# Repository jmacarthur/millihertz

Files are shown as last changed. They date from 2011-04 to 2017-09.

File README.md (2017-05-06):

# Millihertz mechanical computing repository

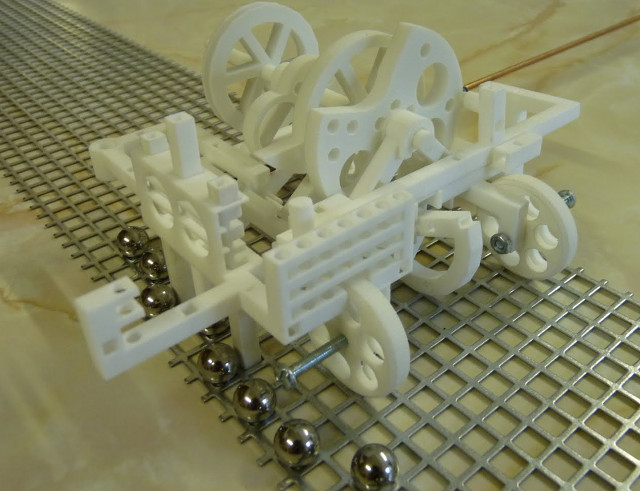
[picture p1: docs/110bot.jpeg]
3D printed rule 110 robot


This is a repository of CAD/CAM parts and text descriptions for mechanical and unusual computing.

* Diagrams: 2D explanatory diagrams, usually for documentation.
* scad: Models used to make Turing machine.
* scad/old: Plans for my first Turing machine, which was largely handmade. Only the 'maze' part of this was actually used in the finished machine.
* scad/newbuild: Plans for the V2 Turing machine, which was laser-cut. The finished V2 machine was closer to the plans, but some post-cutting modifications were still necessary.
* scad/110: Plans for two verions of the rule 110 automaton; one intended for 3d printing and one for laser cutting.

Please note that none of the plans in here are intended for people to make directly. They are likely to be unfinished and contain errors. They are also not very well documented, which may improve over time.

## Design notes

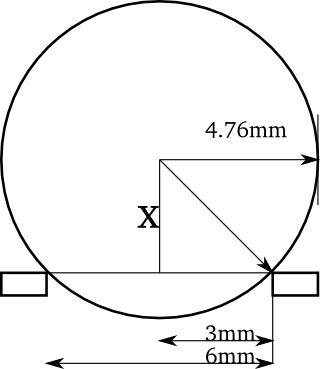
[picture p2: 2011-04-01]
diagrams/ingress.png

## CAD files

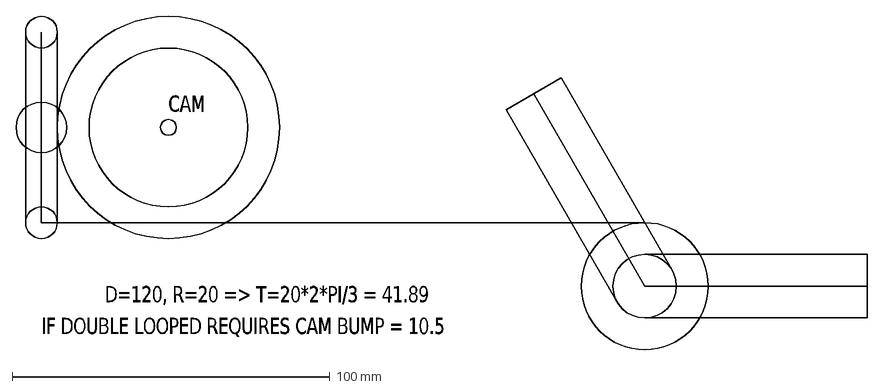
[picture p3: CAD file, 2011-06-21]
diagrams/lifter.dxf
D=120,\~R=20\~=>\~T=20*2*PI/3\~=\~41.89
CAM
IF\~DOUBLE\~LOOPED\~REQUIRES\~CAM\~BUMP\~=\~10.5

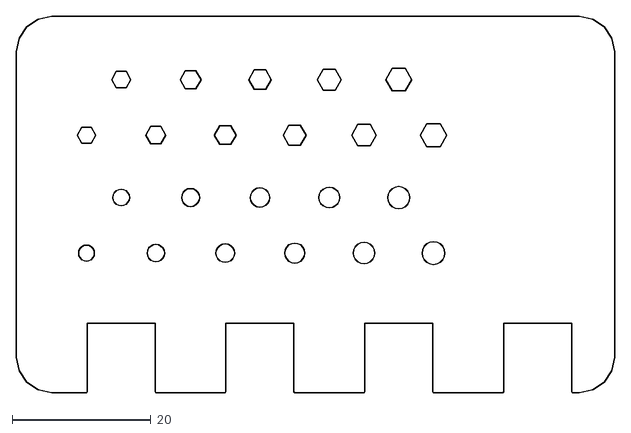
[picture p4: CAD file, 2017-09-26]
scad/laser_test/laser_test_kerf_0.1.dxf
86.2 x 54.2

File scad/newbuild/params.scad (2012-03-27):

// This file should only contain constants (no objects)
// All measurements are in mm

// Grid parameters. This is for 6mm square hole galvanised grid
// RS stock number 210-3729
gridThickness = 1.4; // That's two grid plates on top of each other
gridSpacing = 7.58; // That's the period of the grid, not the hole size
	            // Measured from actual grid
gridHoleSize = 6;
gridWallWidth = gridSpacing - gridHoleSize;


mazeWidth = 115+12;
mazeHeight = 35;
mazeLength = 97;
mazeStartY = 0;

// These define the location of the holes for the raiser axles.
mazeHoleOffsetY = 76.5;
mazeHoleOffsetZ = 13;

dirBoxHeight=10;
dirBoxWallWidth=5;

stateBoxHeight=22;
stateBoxWallWidth=5;

ballRadius = 4.76;

// ballBearingHeight is the top of any ball bearing sitting in the grid.
ballBearingHeight = sqrt(ballRadius*ballRadius - (gridHoleSize/2)*(gridHoleSize/2)) + gridThickness + ballRadius;

// row1x is the X coordinate of the centre of the first row of ball bearings
row1x = gridSpacing*5+gridWallWidth + gridHoleSize/2;
echo("row1x is ",row1x);
// Measured from the original machine
chassisInternalSpacing = 95;
chassisWallThickness = 1.5;
chassisThickness = 20;

wheelDiameter = 37.5;
wheelRadius = wheelDiameter/2;
wheelWidth = 6; // Should be <= gridHoleSize
axleDiameter = 3;
axleRadius = axleDiameter/2;
wheelIngress = sqrt((wheelRadius*wheelRadius)-(gridHoleSize/2)*(gridHoleSize/2));
axleHeight = wheelIngress + gridThickness;

chassisStartX = gridWallWidth+wheelWidth;

chassisTop = axleHeight+axleRadius+chassisThickness;
rideHeight = chassisTop - chassisThickness;

// Standard roller bearing, 5mm bore, 16mm OD
bearingWidth = 5;
bearingRadius = 8;

// Needle roller bearing, 12mm bore, 10mm wide, 16mm OD
// Technobots 4250-007
needleRollerRadius = 8;
needleRollerWidth=10;

raiserWallWidth = 3;
raiserSeparation = 1;
mazeStartX =  gridWallWidth+wheelWidth+chassisThickness-(mazeWidth-chassisInternalSpacing)/2;

axle1Y = gridSpacing*12;
axle2Y = gridSpacing*39;
axleBlockThickness = 3;
axleBearingDiameter = 6; // These are technobots mini bearings, code 4255-020

// Laser beam diameter
// This is set to zero because I expect to account for the laser cut width
// outside OpenSCAD (in InkScape, probably)
cutWidth=0;

// This is used to make things slightly bigger for CSG, to avoid touching walls.
thin = 0.1;

mazeTop = chassisTop+mazeHeight-5;

dirBoxOffsetY = gridSpacing*4-dirBoxWallWidth/2; 
dirBoxOffsetX = row1x-dirBoxWallWidth-gridSpacing; // Offset from the edge of the grid to the dir box

boxWidth = 4.76; // Width of box section used as cam axle

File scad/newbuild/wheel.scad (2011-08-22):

include <params.scad>

// Defines wheels for the Turing machine. Wheels need to fit into holes
// in the grid to provide some keying for the machine's position.

// Wheels are Z adjusted to ride on a double-thickness grid. X,Y are adjusted so without translation, the wheel will fit into the grid hole nearest (0,0).

// The wheels used on the first Turing machine were 37mm "flight wheels"
// from technobots, but these seem to have been discontinued. 

//Technobots do however sell a 38mm wheel which looks appropriate

module wheel()
{
	translate([gridWallWidth,gridWallWidth+gridHoleSize/2,axleHeight]) rotate([0,90,0]) {
	difference() {
    	  cylinder(r=wheelRadius,h=wheelWidth);
	  translate([0,0,-1]) cylinder(r=axleBearingDiameter/2,h=wheelWidth+2);
	}
	}
}

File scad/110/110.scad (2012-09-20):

// First, some global constants.

gridSpacing = 7.58; // The 'period' of the square grid.
gridHoleSize = 6; // Size of the holes in it.
ballDiameter=9.52;
ballRadius = ballDiameter/2;

clearance = 0.2;

// Calculated constants
gridLineWidth = gridSpacing - gridHoleSize;
$fn=20;
$t=(1-$t);

// The grid
module grid()
{
  for (i=[-17:5]) {
    translate([-50,gridSpacing*i+gridHoleSize/2,-1]) cube([100,gridLineWidth,1]);
  }
    
  for (i=[-5:5]) {
    translate([-gridSpacing*i+gridHoleSize/2,-120,-1]) cube([gridLineWidth,150,1]);
  }
}

// A clip-close sleeve for axles
module clipSleeve()
{
  difference() {
    cylinder(r=5,h=5);
    translate([0,0,-1])cylinder(r=2.5+2*clearance,h=12);
    translate([0,-6,-1]) cube([10,12,12]);
    translate([-3,2.5+1.25,-1])cylinder(r=1+clearance,h=20); // Note - only clearance on one side, as I want an interference fit here
    translate([-3,-5+1.25,-1])cylinder(r=1+clearance,h=20);    
  }
}

module clipSleeveA()
{
  union() {
    difference() {
      cylinder(r=5,h=7);
      translate([0,0,-1])cylinder(r=2.5+2*clearance,h=12,$fn=50);
      translate([-10,-6,-1]) cube([10,12,12]);
    }
    translate([-4,2.5+clearance*2,5]) cube([4.1,2.4,2]);
    translate([-4,-5,5]) cube([4.1,2.5-clearance*2,2]);
    translate([-3,2.5+1.25,0])cylinder(r=1,h=7);
    translate([-3,-5+1.25,0])cylinder(r=1,h=7);
  }
}



include <cam1.scad>;
// A simple cam

// Small model bearing from Technobots, stock code 4255-020
module smallBearing()
{
  difference() {
    cylinder(r=3,h=3);
    translate([0,0,-1]) cylinder(r=1.5,h=5);
  }
}

// Place a ball on the grid

// Calculate the recess into the grid...

ballHeight = sqrt(ballRadius*ballRadius - (gridHoleSize/2)*(gridHoleSize/2));

pattern = 7;
bit2 = (pattern>=4)?1:0;
pattern2 = pattern -(bit2*4);
bit1 = (pattern2>=2)?1:0;
pattern3 = pattern2 - (bit1*2);
bit0 = (pattern3>=1)?1:0;

module data()
{
  translate([0,gridSpacing*bit2,ballHeight]) sphere(r=ballRadius, $fn=30);
  translate([gridSpacing*2,gridSpacing*bit1,ballHeight]) sphere(r=ballRadius, $fn=30);
  translate([gridSpacing*4,gridSpacing*bit0,ballHeight]) sphere(r=ballRadius, $fn=30);
   
  // Put a ball out on the sweeper to check alignment
  translate([gridSpacing*2,gridSpacing*-12,ballHeight]) sphere(r=ballRadius, $fn=30);
}

// Now add three 'reader rods'

ballTopZ = ballHeight+(ballRadius);

// Rule 110: 
// Current pattern 111: write 0
// Current pattern X00: write 0
// Otherwise write 1
feelerSize = 4.76;
module feeler()
{
  difference() {
    union()
    {translate([-feelerSize/2,-feelerSize/2,0])
        cube(size=[feelerSize,feelerSize,50]);
    }
    translate([-10,-feelerSize/2-1,35]) cube([50,4,2]);
    translate([-feelerSize/2+1,-feelerSize/2+1,-1]) cube([3,3,30]);
  }  
}

// Notch feeler1
module feeler1()
{
  union() {
    difference()
    {
      feeler();
      translate([-10,-feelerSize/2-1,40]) cube([50,4,2]);
      translate([-10,-feelerSize/2-1,40-ballTopZ]) cube([50,4,2]);
      translate([-feelerSize/2+1,-feelerSize/2+1,40+3]) cube([3,3,30]);
    }
    translate([0,-feelerSize/2+1,10]) rotate([90,0,0]) cylinder(r=2,h=9,$fn=10);
    
  }	  
}

module feeler2()
{
  union()
  {difference()
    {
      feeler();
      translate([-10,-feelerSize/2-1,40-ballTopZ]) cube([50,4,2]);
      translate([-feelerSize/2+1,-feelerSize/2+1,43]) cube([3,3,30]);
    }
    translate([0,-feelerSize/2+1,10]) rotate([90,0,0]) cylinder(r=2,h=9,$fn=10);
    
  }
}

// lever 1
engage1=(pattern==7)?1:0;
module lever()
{
  difference() {
    union() {
      translate([-100,-5,0])
	cube(size=[105,10,2]);
      translate([0,0,-20])cylinder(r=2.5,h=20);
      translate([0,0,-5])cylinder(r=3.5,h=10);
    }
    // Hole for axle
    translate([0,0,-30])cylinder(r=1.5+2*clearance,h=50);
    // Hole for spring attachment
    translate([-83,2,-1]) cylinder(r=1.5,h=4);
    for(x=[1:7]) translate([-10*x,0,-1]) cylinder(r=4,h=4);
    for(x=[0:1]) translate([-78-10*x,-1,-1]) cylinder(r=3,h=4);
    translate([-95,-0,-1]) cylinder(r=3,h=4);
    // Chamfer edges
    translate([-101,5,1.5]) rotate([45,0,0]) cube([100,2,2]);
    translate([-101,7,-4.5]) rotate([45,0,0]) cube([100,5,5]);
  }
  
}

module lever2()
{
  difference() {
    union() {
      translate([-100,-5,0])
	cube(size=[105,10,2]);
      translate([0,0,-15])cylinder(r=1.5,h=15);
    }
    // Hole for spring attachment
    translate([-83,2,-1]) cylinder(r=1.5,h=4);
    for(x=[1:7]) translate([-10*x,0,-1]) cylinder(r=4,h=4);
    for(x=[0:1]) translate([-78-10*x,-1,-1]) cylinder(r=3,h=4);
    translate([-95,-0,-1]) cylinder(r=3,h=4);
    translate([-101,5,1.5]) rotate([45,0,0]) cube([100,5,5]);
    translate([-101,5,-6.5]) rotate([45,0,0]) cube([100,5,5]);
  }
}

leverAxisX = -20+95;
leverAxisY = -10-feelerSize/2+9;


// lever 2
engage2=(pattern==4 || pattern==0)?1:0;

// Tower for mounting springs to
module springTower()
{
  difference()
  {
    union()
    {
      translate([-10,30,25]) squareBarZ(15);
      translate([-10,0,25]) squareBarY(30);
      translate([-10,25,35]) cube([5,10,2]);
      translate([-10,25,40]) cube([5,10,2]);
    }
    translate([-7.5,27.5,0]) cylinder(r=1.5,h=100);
  }
}

wheelRadius = 15;

// guide plate (baseplate)
module basePlate() 
{
  difference() {
    union() {
      translate([-5,-5,25])cube(size=[40,10,5]);
      translate([leverAxisX,leverAxisY,20]) cylinder(r=5,h=10);
      translate([-3.5,-2.5-1,45])cube(size=[gridSpacing*4+7,5+3.5,1]);
      translate([35,-5,25]) squareBarX(40);
      translate([29,-30,25]) squareBarX(45);
      translate([-20,0,25]) squareBarX(20);
      translate([leverAxisX-2.5,-30,25]) squareBarY(30);
      difference() {
        translate([-3.5,4,25])cube(size=[gridSpacing*4+7,1,20]);
        translate([gridSpacing*1,3,37]) rotate([270,0,0]) cylinder(r=7,h=4);
        translate([gridSpacing*3,3,37]) rotate([270,0,0]) cylinder(r=7,h=4);
      }
      translate([-3.5,2.5,35])cube(size=[gridSpacing*4+7,2,1]);
      translate([-3.5,2.5,40])cube(size=[gridSpacing*4+7,2,1]);
    }
    
    // Cut out holes for feelers
    translate([-feelerSize/2-clearance,-feelerSize/2-clearance,-1]) cube([feelerSize+2*clearance,feelerSize+2*clearance,100]);
    translate([gridSpacing*2-feelerSize/2-clearance,-feelerSize/2-clearance,-1]) cube([feelerSize+2*clearance,feelerSize+2*clearance,100]);
    translate([gridSpacing*4-feelerSize/2-clearance,-feelerSize/2-clearance,-1]) cube([feelerSize+2*clearance,feelerSize+2*clearance,100]);
    // Hole for lever axle
    translate([leverAxisX,leverAxisY,-1]) cylinder(r=2.5+clearance*2,h=100);
    
    // Square holes between feelers
    translate([gridSpacing*1-2.5,0-2.5,24]) cube([5,5,12]);
    translate([gridSpacing*3-2.5,0-2.5,24]) cube([5,5,12]);
  }
}

// Wheel
module wheel()
{
  rotate([90,0,0])
    difference() {
    union() {
      cylinder(r1=wheelRadius-1, r2=wheelRadius, h=1,$fn=100);
      translate([0,0,1])cylinder(r=wheelRadius, h=4,$fn=100);
      translate([0,0,5])	cylinder(r1=wheelRadius,r2=wheelRadius-1,h=1,$fn=100);
    }
    // axle bore
    translate([0,0,-1]) cylinder(r=1.5,h=8);
    // Weight reduction
    for(a=[0,60,120,180,240,300])
      translate([wheelRadius*0.6*cos(a),wheelRadius*0.6*sin(a),-1]) cylinder(r=wheelRadius*0.25,h=8);
    translate([0,0,2])cylinder(r=wheelRadius-3, h=2,$fn=10);		
  }
}

// Calculations to do with wheels

wheelIngressAngle = asin((gridHoleSize/2)/wheelRadius);

echo("Calculated wheel ingress angle = ",wheelIngressAngle);

axleHeight = wheelRadius*cos(wheelIngressAngle);

echo("Calculated axleHeight=",axleHeight);
axle1X = -gridSpacing*3;
axle2X = gridSpacing*7;
// Legs
module leg()
{
  color([0.5,0.5,0.5]) {
    difference() {
      translate([axle1X-2.5,0,axleHeight-3]) cube(size=[5,5,25-axleHeight]);
      translate([axle1X,6,axleHeight]) rotate([90,0,0]) cylinder(r=1.5+clearance,h=20,$fn=20);
      translate([axle1X-1.5,1,axleHeight-4]) cube(size=[3,3,28]);
    }
  } 
}

// bed-frame on top of axles (union with body)

module squareBarX(size)
{
  difference() {
    cube(size=[size,5,5]);
    translate([-1,1,1])cube(size=[size+2,3,3]);
    if(size>10) {
      translate([size/2-1,1,-1]) cube(size=[3,3,7]); 
    }
  }
}

module squareBarY(size)
{
  translate([5,0,0]) rotate([0,0,90]) squareBarX(size);
}

module squareBarZ(size)
{
  translate([0,0,size]) rotate([0,90,0]) squareBarX(size);
}
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

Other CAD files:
scad/110/110a.scad
scad/interconnect/2d_interconnect.scad
scad/interconnect/2d_interface.scad
scad/interconnect/interconnect.scad
scad/interconnect/interface.scad
scad/laser_test/laser_test.scad
scad/newbuild/axle.scad
scad/newbuild/cams.scad
scad/newbuild/chassis.scad
scad/newbuild/diramp.scad
scad/newbuild/dirbox.scad
scad/newbuild/engine.scad
scad/newbuild/generated_cams.scad
scad/newbuild/grid.scad
scad/newbuild/lifter.scad
scad/newbuild/liftersupport.scad
scad/newbuild/maze.scad
scad/newbuild/movercam.scad
scad/newbuild/punt.scad
scad/newbuild/reducerpulley.scad
scad/newbuild/returner.scad
scad/newbuild/statebox.scad
scad/newbuild/stateflip.scad
scad/newbuild/toplevel.scad
scad/old/camshaft.scad
scad/old/dirbox.scad
scad/old/liftercam.scad
scad/old/maze.scad
scad/old/mover.scad
scad/old/params.scad
scad/old/raiser.scad
scad/old/skeleton.scad
scad/old/statebox.scad
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

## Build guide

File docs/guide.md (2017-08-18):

# Mechanical computing cookbook

This is a document describing some approaches to mechanical computing.

## Zuse-style sliding plate 

This is a 2-input OR gate. The inputs are made by sliding plates 'A' and 'B' up or down, '1' being up and '0' being down.

```bob

                   ^
                   |
       ^           v
       |      +----------+
       v      | +-----.  |
  +----------+| |      ) | +------------+
  | +-----.  || |  +--'  | | .--------. |
  | |O     ) || |O |     | |(     O    )|
  | |  +--'  || +--+  B  | | '--------'C|
  | |  |     |+----------+ +------------+
  | +--+  A  |                          ^    ^
  +----------+                          0    1 

  .---------------------------------.
 (   O           O                O  ) Drive bar
  '---------------------------------'
 <---
 ------->
     <---   
```

```basicsvg
plate=polygon([[0,0], [50,0], [50,50], [0,50]], [[10,10],[40,10],[40,25],[25,25],[25,40],[10,40]]);
plate2=copy(plate, [61,0]);
```

The 'drive bar' at the bottom has three pegs in it which fit into the points marked 'O' on the moving plates. Cycling the gate requires pushing the rod at the bottom left, then fully right, then back to the centre again. Moving left resets the output to zero. On moving fully right, the output plate C will be pushed if either plate A or B are in the up position. When a plate is in the down position, the peg moves inside the channel without moving the plate. 'A' will push B if B is not being driven, so if either of them move, C will move to '1'. The input plates cannot move vertically while the drive bar is fully right, so the bar must be returned to the centre position before the inputs are updated.

Inversion of the inputs can be easily achieved by turning the input plates upside down; turning both would give you a NAND gate.

## Decoders

A decoder, represented by the circuit symbol below, takes n binary inputs and turns on exactly 1 of 2^n outputs. A 3-to-8 decoder take 3 inputs and lights exactly one of 8 outputs. It's similar to a demultiplexer but with the data input always set to '1'.

```bob
    +  
    |\ 
    | \
    | |--- 0
    | |--- 1
A --|D|--- 2
B --|E|--- 3
C --|C|--- 4
    | |--- 5
    | |--- 6
    | |--- 7
    | /
    |/
    +  
```

A decoder can be made using a set of rods, coded such that a gap opens in exactly one place.

```bob
       0       1       2       3       4       5       6       7
       |       |       |       |       |       |       |       |         
       _       _       _       _____       _       _       _
 A  __| |_____| |_____| |_____|     |_____| |_____| |_____| |_______

       _       _____       _           _       _____       _
 B  __| |_____|     |_____| |_________| |_____|     |_____| |_______

       _____           _____           _____           _____
 C  __|     |_________|     |_________|     |_________|     |_______
    
```

The three input rods A, B and C are shown vertically in the above diagram but would be laid out side-by-side in the decoder, with eight rods laid over the top. The arrangement of bumps on the input rods allows only one rod to fall into a gap at a time; in this case, it's output 7.

Input 'A' blocks rods 0, 1, 2, and 3 in the diagram above, but if it is moved to the right by half the separation distance of the output rods, then it will instead block 4, 5, 6 and 7. Now, instead of rod 7 falling, rod 3 will fall.

Similarly, Input 'B' allows 2,3, 6 and 7 to fall, and if pushed right, will allow 0, 1, 4 and 5 to fall. Input 'C' allows odd-numbered outputs when pushed left, and even-numbered outputs when pushed right.

This can be extended to cope with any number of inputs, but the length of each input rod will be proportional to the 2^n, so 4 or 5 inputs is likely to be the practical limit. The output rods are only driven by gravity, so an amplifier of some sort will probably be necessary.

With the square edged bumps shown above, all output rods must be lifted by another means before the input can be changed. If the bumps are given sloping edges, as below, then it may be possible to do away with that lifting mechanism.

```bob
       _       _       _       _____       _       _       _      
 A  __/ \_____/ \_____/ \_____/     \_____/ \_____/ \_____/ \_______

       _       _____       _           _       _____       _
 B  __/ \_____/     \_____/ \_________/ \_____/     \_____/ \_______

       _____           _____           _____           _____
 C  __/     \_________/     \_________/     \_________/     \_______
```

However, this will require more force from the inputs and may make the input rods longer.

## Array logic

Once a decoder has been constructed, it can be used to make array logic. The diagram below shows the decoder on the left, shown end-on so we are looking in the direction the input rods move in.

```bob
                                     _  _  _
                                    |X||Y||Z|
                                    |_||_||_|
                                  ___^_____^_
                                 |   x  y  z |
    ____________________         |  _________|
   |____________________|        | |       _
   | Decoder output 0   |  ______|o|      |L|
   |____________________| <________|      |2|  
     |A| |B| |C| |D| |L|                  |_|
     |_| |_| |_| |_| |_|

```

'L' is the lifting gear for the input, which lifts all the decoder outputs at once. There are four inputs on this machine, so there will be 16 decoder outputs; decoder 0 output is visible with the other 15 behind it.

The S-shaped part on the right is pivoted at 'o'. The bar L2 will lift all of these up at the start of cycle. All of these will then rotate clockwise - with the large part on the right dropping - except for one, which is blocked by the single decoder rod which has fallen into the gap. Being the only S-shaped part which remains in place, it is the only one which can support the output rods X, Y and Z.

This particular S-shaped piece has bumps on top in the 'x' and 'z' positions, so output rods X and Z will be held up, and Y will drop. X, Y and Z are long bars - roughly the same length as the input rods - and run down the whole length of the machine.

There are 16 S-shaped pieces stacked beside each other, and each can have a different pattern of bumps on top. This pattern of bumps determines the logical function of the machine. These might be made specifically for one function, or you might keep a stock of S-shaped pieces with different bumps to assemble any logic function with.

The outputs X, Y and Z are unpowered, as before, so we may need an amplifier.

### Amplifier for logic arrays

The output rods running the length of the array can be constructed like this:

```svgbob

   <---
   ------->
       <---
   _________________________________________________________
  |____   _______________   ____________   _______________  |
       | |       ___     | |            | |       ___     | |
       |_| _____|   |    |_|            |_| _____|   |    |_|
   _______|         |______________________|         |_________________
  |                                          OUTPUT Y               | o|
  |_________________________________________________________________|__|
     ^   ^   _   _   ^   _   _  |s|  _   ^   _   ^   ^   ^   ^   ^
    |s| |s| |s| |s| |s| |s| |s| |_| |s| |s| |s| |s| |s| |s| |s| |s| 
    |_| |_| |_| |_| |_| |_| |_|     |_| |_| |_| |_| |_| |_| |_| |_|

```

In this diagram , we are looking at a single output rod with 16 S-shaped pieces below it, one of which is up - but this one has no 'bump' for this output rod, so the rod is down.

The rake-shaped part on top moves left, returning the output rod to the left (whether it is up or down. The rake-shaped part then moves to the right, and it will catch the output rod and push it right only if the rod is held up; in the above diagram, the output rod is down so it remains in the '0' position.

There are two L-shaped drive tabs on top of the output rod. This is because the output rod may not be lifted perfectly vertically; if one of hte S-shaped pieces at each end is up, only one end of the output rod may be lifted.

## Interconnects

None of the above system would be much use without a means to connect outputs to inputs. A simple rod might work if the gates or arrays are able to be arranged carefully. For a complex system, Bowden cable - the system usually used for bicycle brake cables - allows for flexible connections between units.

True Bowden cable can transmit high forces and is quite complicated. For our application, lighter and simpler alternatives can be found, such as cable referred to as 'snake' used for control in some model aircraft.

Bowden cable is usually used for tension, that is, only to pull a load. However, cables work quite well when used to push as well. If you want to avoid using a Bowden cable to push loads, you can use two cables with a lever at each end so logical signals can be transmitted as 'pull' for each symbol.

Various connectors exist for terminating the ends of bowden cable, however it is convenient to use the screw terminals from small electrical connection blocks. A simple connector can be made like this:

```bob

     __________________________
    |o                         |
    |_                         |
      |                        |
     _|                        |
    |o    ____________         |
    |_   |   __  __   |        |
      |  |  _||__||_  |   ________________
     _|__| |        |=====________________
    |o     |________| |        |
    |_________________|        |
      |________________________|

```

The top two points marked 'o' are fixed points for connecting to a logic gate chassis. The bottom 'o' moves to determine the logic value. In my system, zero is always marked by the bottom mounting hole being aligned with the top two holes, and the slider moves inwards (towards the cable) by 5mm to indicate a 1, but you can choose any scheme you like.

All the Bowden cables I've seen, including the heavier bicycle cables, have some amount of free play in them which is roughly proportional to the amount they are bent. Bending a basic 'snake' cable through 360 degrees creates free play of 3-4 mm.

Given a difference between '1' and '0' of about 5mm, this would be a big problem. To account for this, we can simply declare the difference between '1' and '0' is longer, but this makes the input rods for a decoder proportionally longer. Instead, we can make a version of the interconnect containing a lever:

```bob
       ________________________
     _|_______________ ________|
    |o      o    |    |        |
    |_______ \ __|____|        |
      |       \                |
     _|        x               |___________
    |o          \     ____________         |
    |_           \   |   __  __   |        |
      |           \  |  _||__||_  |    _______________
     _|            \_| |        |=====|_______________
    |o            | o  |________| |        |
    |_            |_______________|        |
      |____________________________________|

```

The output on this connector is on top, and the two fixed connectors on the bottom, but it can simply be connected to an existing logic gate upside down.

The point 'x' is a pivot, and a lever, with slots at each end, connects the cable connector to the output shaft. In this way, a cable movement of 20mm can be easily converted to an output of 5mm. Care must be taken to assemble this connector such that it doesn't introduce any significant extra free play of its own.

## Memory

Memory can be created using discrete logic gates but there are more efficient approaches which allow data to be stored with fewer moving parts and less space.

Sequential access memory, as used by a Turing machine or other cellular automata, is quite simple to produce and can be produced with stock parts such as ball bearings and premade steel grid.

Random access memory is more complicated, but can be made in part using decoders as described previously.

### 1D array memory

A decoder as mentioned previously can scale to 32 outputs, which is sufficient for a simple computer - the Manchester SSEM had 32 words of 32 bits each.

The following structure can be made of acrylic, with ball bearings representing the data, normally resting in square cutouts. The whole structure must be verticle, or on a gentle slope, so that the ball bearings fall to the bottom (the 'OUT' end)

```bob
                           IN
                _| |   _| |   _| |   _| |
              _|o  |  |o  |  |o  |  |   |
             / |_  |  |_  |  |_  |  |_  | 
            /    | |    | |    | |    | |
           /    _| |   _| |   _| |   _| |
       /| / ___|   |  |   |  |o  |  |o  |
      /D|/ /   |_  |  |_  |  |_  |  |_  | 
     | E|_/      | |    | |    | |    | |
     | C|_      _| |   _| |   _| |   _| |
      \ |\\____|   |  |o  |  |   |  |o  |
      |\| \    |_  |  |_  |  |_  |  |_  | 
      ||   \     | |    | |    | |    | |
      ||    \   _| |   _| |   _| |   _| |
      ||     \_|   |  |o  |  |   |  |   |
               |_  |  |_  |  |_  |  |_  | 
                 | |    | |    | |    | |
		           OUT
```

To read the data, the decoder must trigger a mechanism which pushes each ball bearing on that row into the channel to its right; the pattern of data for that word will then fall out of the bottom of the mechanism. A mechanism at the bottom will sense the presence or absence of a ball bearing for each column and send this as a logic signal using a standard interconnect.

To write data back in, the decoder must insert a ramp-shaped piece into the vertical column which will divert a falling ball bearing back into the cut-out space on the left. Ball bearings representing the word to write are then dropped into the mechanism at the top, and these will fall past all columns until the selected one, at which point the ball bearings are diverted by the ramp.

The rows in this memory will contain a row of shapes like this:

```bob
     _____             _____             _____             _____
_ _ /     | _ _ _ _ _ /     | _ _ _ _ _ /     | _ _ _ _ _ /     |
   /______|          /______|          /______|          /______|

```

These shapes must be linked together by a connecting rod which is placed at a layer above these shapes, so that ball bearings can pass underneath.

On reading, the row bar is pushed right, and the square edge of this pushes a ball bearing out of its notch and down the channel. To write, the whole bar is moved left so that the ramp-shaped piece can deflect a ball bearing dropping into a notch to the left.

### 2D array memory

By using a 3-to-8 decoder which selects one row and another which selects a column, a 2-dimensional 64-bit array can be created. It's then necessary to create some interaction between a selected row and selected column such that one cell can be accessed independently.

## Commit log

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2011-04-12 Adding newbuild directory, initial files
    [grid.scad, params.scad, toplevel.scad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]
2011-04-12 Added stock number to grid file
    [params.scad]
2011-04-12 Added chassis (not final)
    [chassis.scad, params.scad, toplevel.scad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]
2011-04-13 Added maze (description only)
    [maze.scad]
2011-04-19 Modified chassis with measurements from machine
    [chassis.scad]
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2011-04-19 Lots of changes, mainly lifter and state/dir box
    [dirbox.scad, lifter.scad, maze.scad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]
2011-04-23 Refactored, added lip on maze
    [maze.scad, params.scad, toplevel.scad]
2011-04-23 Finishing dir flipper. untested
    [dirbox.scad, params.scad, toplevel.scad]
2011-04-23 Added state flip, corrected syntax error in dir box.
    [dirbox.scad, stateflip.scad, toplevel.scad]
2011-06-20 Mad Men Sunday Things
    [chassis.scad, diramp.scad, dirbox.scad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]
2011-06-21 More work on V2 + diagrams
    [cams.scad, lifter.dxf]
2011-08-10 More refinements and simplification
    [axle.scad, cams.scad, generated_cams.scad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]
2011-08-11 Added lifter pullers, restructured lifter x positions
    [lifter.scad, liftersupport.scad, params.scad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]
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2011-08-22 Constructed lifter supports properly, coloured some parts
    [chassis.scad, lifter.scad, liftersupport.scad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]
2011-12-04 Added direction selector; cams coloured; lifter support no longer rotates; dir-reset rod support
    [cams.scad, chassis.scad, dirbox.scad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]
2011-12-04 Steam engine and reducer pulley
    [chassis.scad, engine.scad, reducerpulley.scad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]
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2012-01-23 Acrylic chassis; wheels moved
    [chassis.scad, params.scad, toplevel.scad]
2012-01-23 Returner ready for cutting
    [chassis.scad, params.scad, returner.scad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]
2012-01-24 Added axle blocks to chassis
    [axle.scad, chassis.scad, toplevel.scad]
2012-01-25 Added tabs, vertical slide to punt
    [punt.scad, toplevel.scad]
2012-02-04 Properly indented toplevel.scad, reorganised a bit
    [toplevel.scad]
2012-02-04 Set laser cut width to 0
    [params.scad, toplevel.scad]
2012-02-04 More rearrangement of toplevel
    [toplevel.scad]
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2012-02-04 Drilled holes in chassis for returner
    [chassis.scad, params.scad]
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2012-02-05 Dir box & state box now interlock
    [dirbox.scad, params.scad, statebox.scad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]
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2012-02-05 Finished dir-amp & support
    [diramp.scad, dirbox.scad, statebox.scad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]
2012-02-05 Add punt plate location tabs and refactor
    [punt.scad, toplevel.scad]
2012-02-05 Add tabs to chassis for punt plate
    [chassis.scad]
2012-02-05 Add stop bars to second lifter; reformat
    [lifter.scad, toplevel.scad]
2012-02-07 Initial work on animation
    [cams.scad, toplevel.scad]
2012-02-17 More cam work; lifter cams adjusted
    [cams.scad, generated_cams.scad, lifter.scad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]
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2012-03-08 Put 1st reducer somewhere more sensible; moved second axle back
    [cams.scad, params.scad, reducerpulley.scad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]
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2012-03-08 New input sprocket position
    [reducerpulley.scad]
2012-03-09 Modified punt to attach grading plate
    [punt.scad]
2012-03-09 Removed tabs from second lifter
    [lifter.scad]
2012-03-09 Pulley belt length calculations
    [reducerpulley.scad]
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2012-03-14 Fixed syntax error in lifter.scad
    [lifter.scad]
2012-03-21 Reordered objects in follower
    [cams.scad]
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2012-03-21 All sorts, fixed cams for output; cams are now backwards
    [cams.scad, generated_cams.scad, toplevel.scad]
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2012-03-26 Added holes for boss to cams; moved cam supports to chassis bars
    [cams.scad, chassis.scad, generated_cams.scad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]
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2012-03-27 Refactored lifters to allow unioning of drop bar
    [lifter.scad]
2012-03-27 Fixed returner support plate
    [returner.scad]
2012-03-27 Fixed impossible-to-laser raiser and corrected bearing radius
    [chassis.scad, lifter.scad, params.scad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]
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2012-09-19 Fixed include directive
    [110.scad]
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2012-09-23 Reverse and bellcrank fixes
    [110a.scad]
2013-05-09 Added slot locators for arms; removed drop on crossbeam
    [110a.scad]
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2013-05-09 Moved top plate up so it connects on top
    [110a.scad]
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2013-05-10 Added lid to the large lifter to square it up
    [110a.scad]
2013-05-15 Made clearances for lifters and cams
    [110a.scad]
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2013-07-11 Altering hexagonPrism to avoid scaling
    [110a.scad]
2013-07-11 Fixing use of hexagonPrism to use new size
    [110a.scad]
2013-07-11 Fixing lugs for top plate
    [110a.scad]
2013-07-11 Actually correctly fix top plate mounting lugs
    [110a.scad]
2013-07-14 Fixing camshaft size
    [110a.scad]
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2013-08-05 Fixed small reader arm, small refactor
    [110a.scad]
2013-08-05 Fixing pusher
    [110a.scad]
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2013-08-05 Fix bellcrank tab size, make camshaft holes slightly smaller
    [110a.scad]
2013-08-06 Fixing clearance on slots
    [110a.scad]
2013-08-06 Minor whitespace fixes
    [110a.scad]
2013-08-17 Adding anti-tristate bar, shorten output bar, make notches in reader arms
    [110a.scad]
2013-08-17 Fixing some whitespace.
    [110a.scad]
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2013-08-18 Tab for antitristate bar, whitespace fixes
    [110a.scad]
2013-08-18 Moving crossbeam tabs to work around bug in process.pl
    [110a.scad]
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2017-05-06 Shorten seesaw bars
    [selector.scad]
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2017-05-06 Tweaks to comb units and comments on readout bars
    [selector.scad]
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2017-05-06 Small fixes to tabs
    [selector.scad]
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2017-05-06 Replace enumerator rods with extrusions
    [selector.scad]
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2017-05-08 Add some comments and change the name of 'seesaw' to 'follower'
    [selector.scad]
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2017-05-21 Thin side-bars on row rods to fit into selectors
    [ram.scad]
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2017-05-30 Change output bars to 2D and add to 2D layout
    [2d_assembly_a4.scad, selector.scad]
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2017-05-30 Adjust top end of columns to make data injection easier
    [ram.scad]
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2017-06-04 Document and correct some of the xBars and cutaways
    [selector.scad]
2017-06-04 Adjust front panel to accomodate output hard points
    [selector.scad]
2017-06-04 Cut holes in the front panel for hard points
    [selector.scad]
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2017-06-07 Correct switch spacing calculations and increase to 15mm
    [interface.scad]
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2017-06-11 Fix overlap on front panel
    [interface.scad]
2017-06-12 Correct connector body height
    [interconnect.scad]
2017-06-12 Rewrite of interconnect to allow 4:1 drive ratio
    [interconnect.scad]
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2017-06-18 Add a small peg hole to drive the rows
    [ram-3d.scad, ram.scad]
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2017-06-19 Shorten column x distance; add column reset rod
    [ram-3d.scad, ram.scad]
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2017-06-19 Row selector slots and whitespace fixes
    [globs.scad, ram-3d.scad, ram.scad]
2017-06-19 Whitespace fixes
    [ram-3d.scad]
2017-06-19 Fix row bar raiser
    [ram-3d.scad, ram.scad]
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2017-06-19 Some realignment for tool board and feet for y-axis combs
    [ram-3d.scad, ram.scad]
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2017-06-22 Add new reset rod under the backing plate
    [ram-3d.scad, ram.scad]
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2017-06-23 Correct row enumerators so they use row_y_spacing instead of column_x_spacing
    [globs.scad, ram-2d.scad]
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2017-06-28 Add drive support for the selector, plus whitespace cleanup
    [interconnect.scad, selector.scad]
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2017-07-01 Corrections to selector 2d
    [2d_assembly_a4.scad]
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2017-07-03 Add the possibility of an exploded view of the interconnect
    [interconnect.scad]
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2017-07-03 Adjust ends of output rods to better fit into the chassis
    [selector.scad]
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2017-07-04 Fix lever lifter issues; update notes
    [selector.scad]
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2017-07-12 Input cleanup: decrease travel range, fix hardpoints, make gap to add enumerators
    [selector.scad]
2017-07-16 Adjust drive plate and output rods to suit 20mm travel
    [selector.scad]
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2017-07-16 Add lug to drive plate so it can be driven directly
    [selector.scad]
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2017-07-16 Add selector/interconnect assembly file and add the first connector
    [interconnect.scad, selector-with-interfaces.scad, selector.scad]
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2017-07-19 Add a basic interconnect which takes 20mm travel, for outputs
    [interconnect.scad]
2017-07-19 Remove stagger from output and add output interconnects
    [selector-with-interfaces.scad, selector.scad]
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2017-07-21 Quick fixes for some of the 2d layouts
    [2d_assembly_a4.scad, 2d_interconnect.scad]
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2017-09-26 Add rendered DXF and SVG laser test files at kerf 0.1mm
    [laser_test_kerf_0.1.dxf]
